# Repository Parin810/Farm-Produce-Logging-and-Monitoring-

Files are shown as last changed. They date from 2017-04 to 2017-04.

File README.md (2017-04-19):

# eYSIP-2016-Farm-Produce-Logging-and-Monitoring

#####This project consist of following folders
 **Final code:** This folder contains all the final and documented code
 
 **tests:** This folder contains all the programs file which is used to test the different component
 
 **shop:** Contains all the files related to opencart website

 **Weighing Machine Design:** Contains all the solidworks cad file for design of our weighing platform. It also contains DXF files for laser cutting parts inside lasercut folder.
 
 **User Manual:** contains the guidlines, how to use the product.
 
 **Poster:** Contains png and svg file for final poster
 
 **Final report:** Contains latex porject for final report
 
 **progress-presentation-1:** Latex project for first presentation

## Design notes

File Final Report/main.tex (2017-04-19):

\documentclass[a4paper,12pt,oneside]{book}

%-------------------------------Start of the Preable------------------------------------------------
\usepackage[english]{babel}
\usepackage{blindtext}
%packagr for hyperlinks
\usepackage{hyperref}
\hypersetup{
    colorlinks=true,
    linkcolor=blue,
    filecolor=magenta,      
    urlcolor=cyan,
}

\urlstyle{same}
%use of package fancy header
\usepackage{fancyhdr}
\setlength\headheight{26pt}
\fancyhf{}
%\rhead{\includegraphics[width=1cm]{logo}}
%\lhead{\rightmark}
%\rhead{\includegraphics[width=1cm]{logo}}
\fancyfoot[RE, RO]{\thepage}
\fancyfoot[CE, CO]{\href{http://www.e-yantra.org}{www.e-yantra.org}}

\pagestyle{fancy}

%use of package for section title formatting
\usepackage{titlesec}
\titleformat{\chapter}
  {\Large\bfseries} % format
  {}                % label
  {0pt}             % sep
  {\huge}           % before-code
 
%use of package tcolorbox for colorful textbox
\usepackage[most]{tcolorbox}
\tcbset{colback=cyan!5!white,colframe=cyan!75!black,halign title = flush center}

\newtcolorbox{mybox}[1]{colback=cyan!5!white,
colframe=cyan!75!black,fonttitle=\bfseries,
title=\textbf{\Large{#1}}}

%use of package marginnote for notes in margin
\usepackage{marginnote}

%use of packgage watermark for pages
%\usepackage{draftwatermark}
%\SetWatermarkText{\includegraphics{logo}}
\usepackage[scale=2,opacity=0.1,angle=0]{background}
\backgroundsetup{
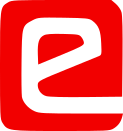
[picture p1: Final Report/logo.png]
contents={}
}

%use of newcommand for keywords color
\usepackage{xcolor}
\newcommand{\keyword}[1]{\textcolor{red}{\textbf{#1}}}

%package for inserting pictures
\usepackage{graphicx}

%package for highlighting
\usepackage{color,soul}

%new command for table
\newcommand{\head}[1]{\textnormal{\textbf{#1}}}

%----------------------End of the Preamble---------------------------------------

\begin{document}

%---------------------Title Page------------------------------------------------
\begin{titlepage}
\raggedright
{\Large eYSIP2016\\[1cm]}
{\Huge\scshape Farm Produce: Logging And Monitoring \\[.1in]}
\vfill
\begin{flushright}
{\large Bhavesh Jadav \\}
{\large Ankur Panwar \\}
{\large MENTORS\hspace{.1in}:}
{\large Saurav Shandilya\\}
{\large Parin Chheda\\}
{\Large Vishwanathan\\}
{\large Duration of Internship: $ 27/05/2016-10/07/2016 $ \\}
\end{flushright}

{\itshape 2016, e-Yantra Publication}
\end{titlepage}
%-------------------------------------------------------------------------------

\chapter[Project Tag]{Farm Produce: Logging And \\ Monitoring}
\section*{Abstract}
This project logs crop data in a green house to reduce manual labour. Essentially, it is a weighing machine connected to Internet.\\
A weighing machine will be delivered to user which can measure weight of crop by using load cell. User can input information related to crop via keypad. User will be assisted by continuous messages on screen. After successful data entry the data will automatically pushed to database. Local people can also take advantage of crop production by placing order through e-commerce website after filling details.

\subsection*{Completion Status}
The project is successfully completed providing "weighing platform, screen, keypad, e-commerce website, admin-panel and user manual." 

\section{Hardware Parts}
\begin{itemize}
  \item Hardware parts
    \begin{itemize}
      \item Load cell
      \item 20x4 LCD
      \item 4x4 Keypad
      \item Raspberry pi 2 Model B
      \item LM2596 step-down voltage regulator
      \item HX711(ADC amplifier)
      \item USB Camera
      \item DC Adapter
      \item Enclosure to hold all parts
    \end{itemize}
  \item Detail of each hardware:\\
    \href{https://cdn.sparkfun.com/datasheets/Sensors/ForceFlex/hx711_english.pdf}{HX711 ADC Amplifier}\\
    \href{http://www.kadcontrols.com/KadWebsite/LoadCell_Tech/CZL601.pdf}{Load cell CZL601}\\
    \href{http://www.onsemi.com/pub_link/Collateral/LM2596-D.PDF}{Step down voltage regulator}\\
    \href{http://lispol.com/uploaded/products_files/1364491305_79923300.pdf}{20x4 LCD}\\
    \href{https://www.parallax.com/sites/default/files/downloads/27899-4x4-Matrix-Membrane-Keypad-v1.2.p    df}{Membrane Keypad}\\
     \href{https://cdn-shop.adafruit.com/pdfs/raspberrypi2modelb.pdf}{Raspberry pi 2 Model B}\\
     \href{https://www.parallax.com/sites/default/files/downloads/27899-4x4-Matrix-Membrane-Keypad-v1.2.pdf}{4x4 Keypad}\\
  
\end{itemize}

\section{Software Used}
\begin{itemize}
   \item List of software used
  \begin{itemize}
   \item  win32 disk imager
   \item  Raspbian wheezy
   \item Notepad++
   \item Local server(xampp apache)
   \item Mysql(xampp)
   \item Diptrace
   \item Corel draw
   \item Autodesk Autocad
   \item Solidworks
   \item Atom text editor
   \item Opencart framework
  \end{itemize}
\end{itemize} 
\begin{itemize}
   \item link of software: \\
  \href{https://sourceforge.net/projects/win32diskimager/}{win32 disk imager}\\
  \href{https://www.raspberrypi.org/downloads/}{Raspbian OS}\\
  \href{https://www.apachefriends.org/download.html}{Xampp}\\
  \href{https://notepad-plus-plus.org/download/v6.9.2.html}{Notepad++}\\
  \href{http://diptrace.com/download-diptrace/}{Diptrace}
\end{itemize}

\section{Assembly Of Hardware}
\subsection*{Dimensions Of Enclosure}
\begin{figure}[!htb]
\minipage{0.24\textwidth}
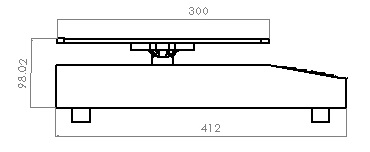
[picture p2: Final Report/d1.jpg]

\caption{Side View}
\endminipage\hfill
\minipage{0.24\textwidth}
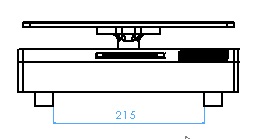
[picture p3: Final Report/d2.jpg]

\caption{Front View}
\endminipage\hfill
\minipage{0.24\textwidth}

\caption{Bottom View}
\endminipage
\end{figure}}
\begin{figure}[!htb]
\minipage{0.24\textwidth}
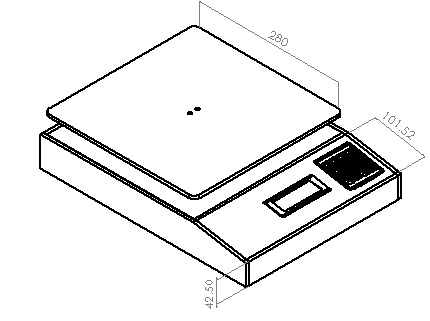
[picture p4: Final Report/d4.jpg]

\caption{Isometric View}
\endminipage\hfill
\minipage{0.24\textwidth}
%\includegraphics[width=\linewidth]{d2.jpg}
%\caption{Front View}
\endminipage\hfill
\minipage{0.24\textwidth}
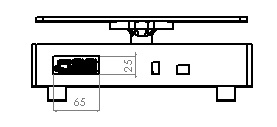
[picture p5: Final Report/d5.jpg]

\caption{Back View}
\endminipage
\end{figure}}
\subsection*{Block Diagram}

\subsection*{Connection Diagram}\\\\
\begin{figure}[!htb]
\minipage{0.24\textwidth}
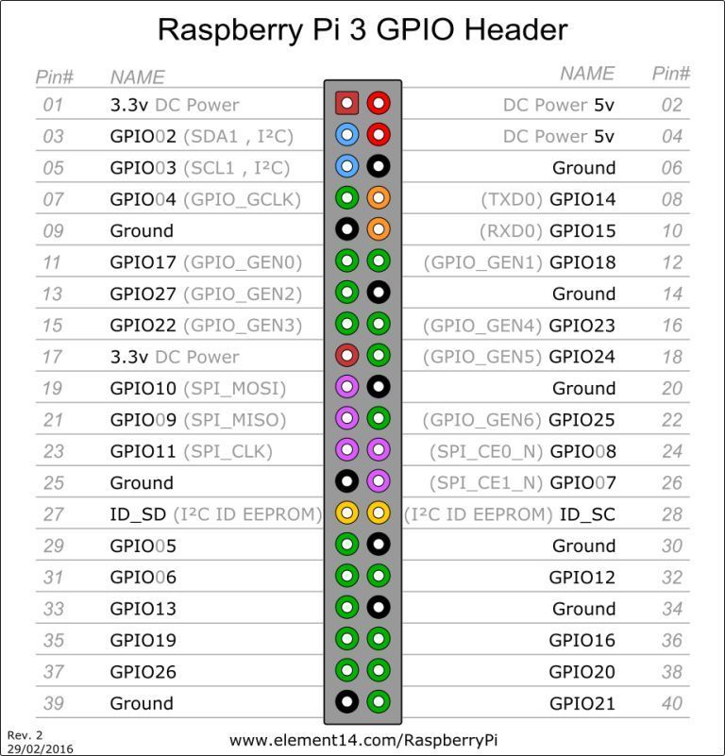
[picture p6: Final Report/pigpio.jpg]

\caption{Rpi pin-out}
\endminipage\hfill
\minipage{0.24\textwidth}
%\includegraphics[width=2cm,height=2cm]{lcd.png}
%\caption{LCD pin-out}
\endminipage\hfill
\minipage{0.24\textwidth}
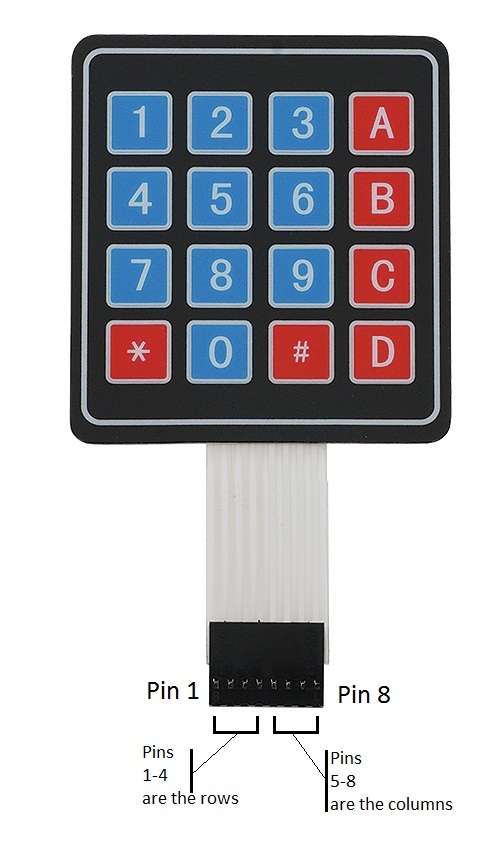
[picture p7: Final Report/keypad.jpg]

\caption{Keypad pin-out}
\endminipage
\end{figure}}
%\item Raspberry pi pinout \includegraphics[height=7cm,width=6cm]{pigpio.jpg}\\

\begin{figure}[!htb]
\minipage{0.24\textwidth}
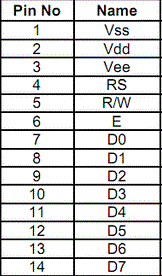
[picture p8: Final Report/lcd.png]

\caption{LCD pin-out}
\endminipage\hfill
\minipage{0.24\textwidth}
%\includegraphics[width=2cm,height=2cm]{lcd.png}
%\caption{LCD pin-out}
\endminipage\hfill
\minipage{0.24\textwidth}

\caption{load cell pin-out}
\endminipage
\end{figure}}

\subsection{Schematic Interface Between Modules}
\begin{figure}[!htb]
\minipage{0.24\textwidth}
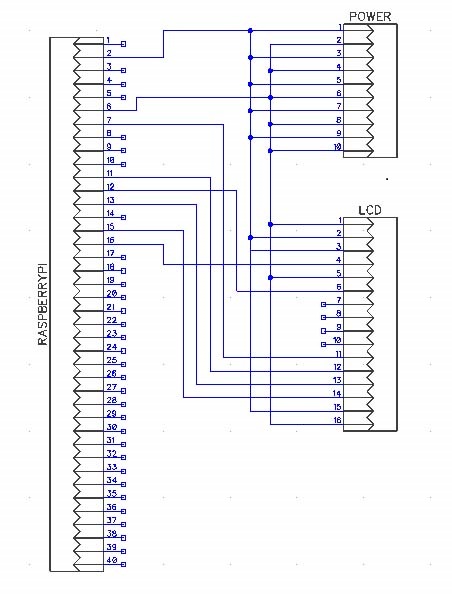
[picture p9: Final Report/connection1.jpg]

\caption{Rpi, power and LCD}
\endminipage\hfill
\minipage{0.24\textwidth}

\caption{Rpi and Load cell}
\endminipage\hfill
\minipage{0.24\textwidth}
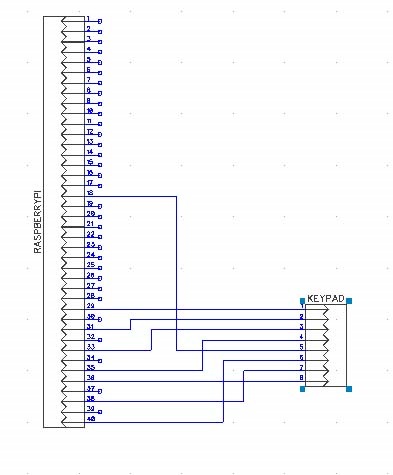
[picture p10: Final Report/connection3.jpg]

\caption{Rpi and keypad}
\endminipage
\end{figure}}
%\item Keypad pinout \includegraphics[height=12cm, width=7cm]{keypad.jpg}\\

\section{Software And Code}
\href{https://github.com/eYSIP-2016/eYSIP-2016-Farm-Produce-Logging-and-Monitoring/tree/master}{Github link}\\\\
e-Commerce website\\\\
\\

\subsection*{Assembling Steps}
The dimension of the machine is 40x30x11.5cm. More detailed version of model can be found on github.\\\\
\\
Step 1: Attach side plates, front plate, middle plate and back plate by using L clamps as shown in above diagram.\\\\\\
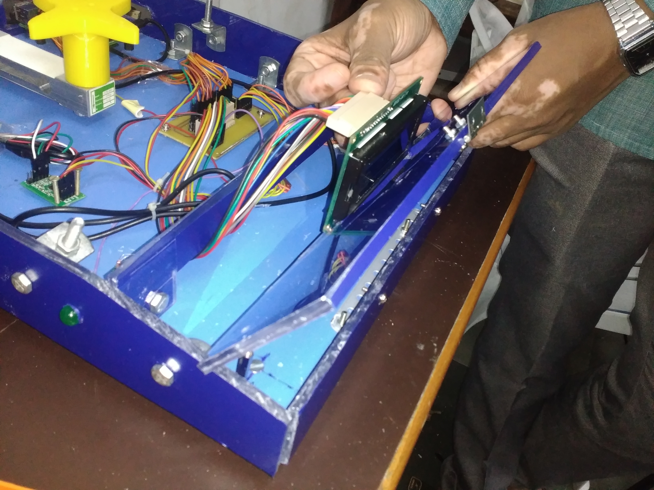
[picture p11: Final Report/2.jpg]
\\
Step 2: Place LCD on front panel. Use 20x4 LCD.\\
\\
Step 3: Use four 3mm screws with bolts to fix the LCD on panel. After attaching LCD, Attach keypad to the front panel\\\\\\
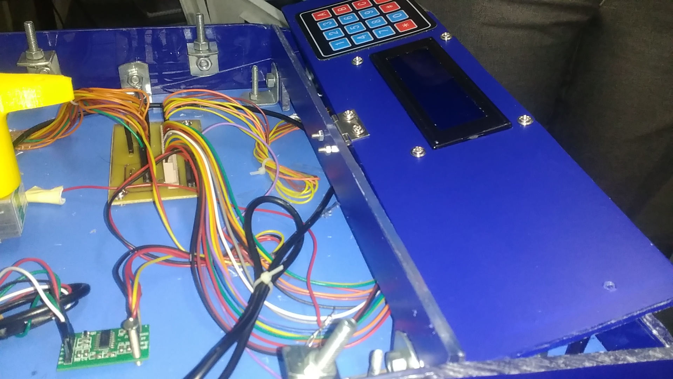
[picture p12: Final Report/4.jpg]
\\
Step 4: Attach front panel to the middle plate with the help of hinge. Use 3mm screws with bolts to attach front panel to middle plate.\\
\\
Step 5: After attaching front panel, place the second top most plate over 4 screws attached with side plates. After
putting the plate, user four nuts to fix the plate.\\\\\\
\\ 
Step 6: Attach weighing platform on top of star shaped design and use 3mm screws with nuts to fix it.\\
\\
Step 7: Finlay attach camera stand at side of the machine.\\

\section{Final Product}
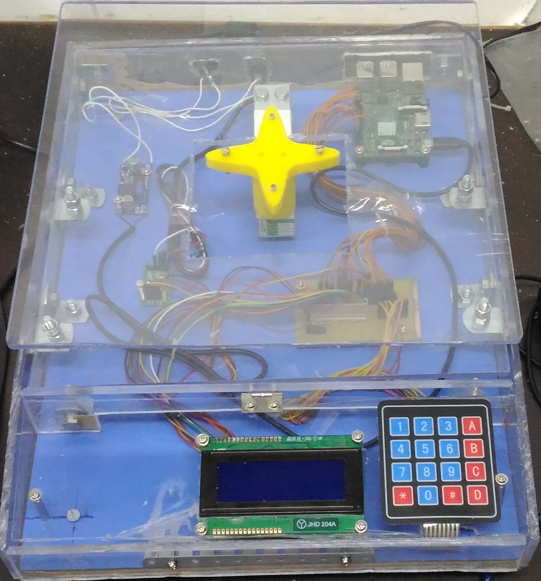
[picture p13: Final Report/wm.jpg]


\section{Future Work}
In future this project can be made more effective by using image processing to identify which crop is put on the machine. We can also include bar-code or RFID module which will contain all the information about crop.\\
We can replace membrane keypad and LCD by touch screen.\\
This model can be transformed into more compact version.\\

\section{Bug Report And Challenges}
\begin{itemize}
\item Bug
\begin{itemize}
   \item Currently e-commerce website is unable to sent email to users using SMTP server.
   \item Two way handshaking between server and machine is not implemented yet. Although it is a rare situation, data might get lost some times while transferring it to server because tow way hand shaking is not implemented yet
\end{itemize}
\item Challenges
\begin{itemize}
   \item Building enclosure of weighing machine.
   \item Calibration of load cell.
   \item De-bouncing of keypad.
\end{itemize}
\end{itemize}
\begin{thebibliography}{li}
\bibitem{wavelan97} eyantra community\\
\bibitem{wavelan97} https://grabcad.com/library/keypad-4x4-membrane-1\\
\bibitem{wavelan97} http://www.tutorialspoint.com/python/python\_functions\\
\bibitem{wavelan97} http://www.tutorialspoint.com/python/python\_database\_access\\
\bibitem{wavelan97} https://grabcad.com/library/20x4-lcd-1\\
\bibitem{wavelan97} https://grabcad.com/library/raspberry-pi-model-b-2\\
\bibitem{wavelan97} http://forum.opencart.com/\\
\bibitem{wavelan97} http://stackoverflow.com/\\
\bibitem{wavelan97} https://sourceforge.net/p/raspberry-gpio-python/wiki/Inputs/\\
\bibitem{wavelan97} https://www.stewright.me/2014/06/tutorial-install-mysql-server-on-raspberry-pi/\\
\bibitem{wavelan97} https://pyformat.info/\\
\bibitem{wavelan97} http://mysql-python.sourceforge.net/MySQLdb.html\\
\bibitem{wavelan97} https://www.youtube.com/watch?v=nGUpzwEa4vg\\
\bibitem{wavelan97} https://www.youtube.com/watch?v=yYnX5QodqQ4\\
\bibitem{wavelan97} http://playground.arduino.cc/Learning/SoftwareDebounce\\
\bibitem{wavelan97} http://www.raspberrypi-spy.co.uk/2012/07/16x2-lcd-module-control-using-python/\\
\bibitem{wavelan97} http://code.stephenmorley.org/php/creating-downloadable-csv-files/\\
\bibitem{wavelan97} http://www.opencart.com/index.php?route=extension/extension/info\&extension\_id=24594\\
\end{thebibliography}

\end{document}

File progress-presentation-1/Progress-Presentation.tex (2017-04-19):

\documentclass[10pt, a4paper]{beamer}
\usetheme{Berkeley}
\usecolortheme{sidebartab}
\usepackage{graphicx}

\begin{document}
	\setbeamertemplate{sidebar left}{}
	\title{Progress Presentation-II}
	\subtitle{e-Yantra Summer Intership-2016 \\FARM PRODUCE: LOGGING AND MONITORING}
	\author{Bhavesh\\Ankur\\$ $\\$ $ \hspace{-0.7in} Mentors: Saurav\\Parin\\Vishwanathan}
	\institute{IIT Bombay}
	\date{\today}
	%\addtobeamertemplate{sidebar left}{}{\includegraphics[scale = 0.3]{logowithtext.png}}
	\frame{\titlepage}

\setbeamertemplate{sidebar left}[sidebar theme]
\section{Overview of Project}
\begin{frame}{Overview of Project}
	Details Of Project: \\
	\begin{itemize}
		\item NAME: \hspace{0.1in} Farm Produce:Logging And Monitoring

		\item OBJECTIVE:\hspace{0.1in}To help in manual record maintenance which is\\$ $\hspace{0.85in} vulnerable to errors by providing a robust\\$ $\hspace{0.85in} automated system. 
		
		\item Deliverables
		\begin{itemize}
			\item LCD
			\item Keypad
			\item Weighing platform
			\item Interactive web page
		\end{itemize}
	\end{itemize}
\end{frame}

\section{Overview of Task}
\begin{frame}{Overview of Task}
	\begin{tabular}{|c|c|C|}
		\hline	
		Week&Task&Deadline\\	
		\hline\hline
		Week1&Raspberry Pi setup and load cell calibration&-\\
		\hline\hline
		Week2&Interfacing 16*2 LCD and 4*4 Keypad&-\\
		\hline\hline
		Week3&1.Integration of Load cell, Keypad and LCD&-\\
		$   $&2.Image capturing from camera and store it in &$ $ \\
		$   $&a database using sql query&$ $\\
		$   $&3.Inserting data into sql database using python&$ $\\
		\hline\hline
		Week4&1.Integration of all the components&-\\
		$   $&2.web interface showing the weight log and image&$ $\\
		\hline\hline
		Week5&1.Adding features like charts and CSV download&6 days\\
		$	$&2.Assembling the entire project with enclosure&$ $\\
		\hline\hline
		Week6&Testing and documentation&6 days\\
		\hline			
	\end{tabular}
\end{frame}

\section{Task Accomplised}
\begin{frame}{Task Accomplised}
	\textbf{Completed Tasks}
	\begin{itemize}		
		\item Raspberry Pi setup and load cell calibration
		\item Interfacing 16*2 LCD and 4* Keypad
		\item Integration of load cell, Keypad and LCD 
		\item Image capturing from camera and storing in database
		\item Inserting data into sql database using python
		\item Integration of all the components
		\item Web interface showing the weight log and image
	\end{itemize}	
		\textbf{Tasks Left}
	\begin{itemize}	
		\item Adding features like charts and CSV
		\item Assembling the entire project with enclosure
		\item Testing and documentation
	\end{itemize}
\end{frame}

\section{Challenges Faced}
\begin{frame}{Challenges Faced}
	\begin{itemize}
		\item LOAD CELL:\hspace{.1in} Caliberation
		\item LCD:\hspace{.1in} Clear screen
		\item KEYPAD:\hspace{.1in} Debouncing
	\end{itemize}
\end{frame}

\section{Future Plans}
\begin{frame}{Future Plans}
	\begin{itemize}
		\item In future, team is planning to replace LCD and Keypad by Touch screen. 
	\end{itemize}
\end{frame}

\section{Thank You}
\begin{frame}{Thank You}
	\centering THANK YOU !!!
\end{frame}
\end{document}

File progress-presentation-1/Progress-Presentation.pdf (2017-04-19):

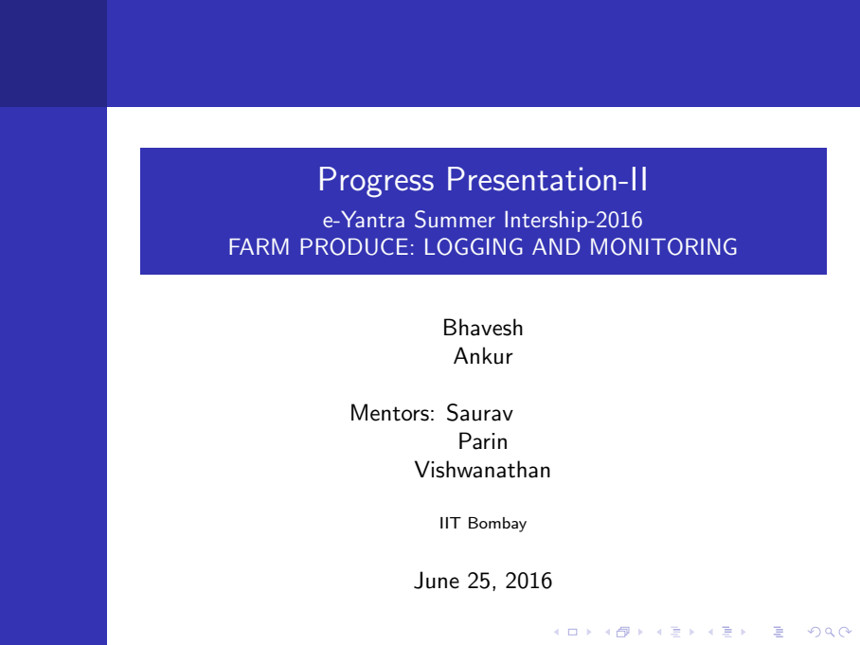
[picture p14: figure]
Progress Presentation-II; e-Yantra Summer Intership-2016 FARM PRODUCE: LOGGING AND MONITORING; Bhavesh Ankur; Mentors: Saurav Parin Vishwanathan; IIT Bombay; June 25, 2016

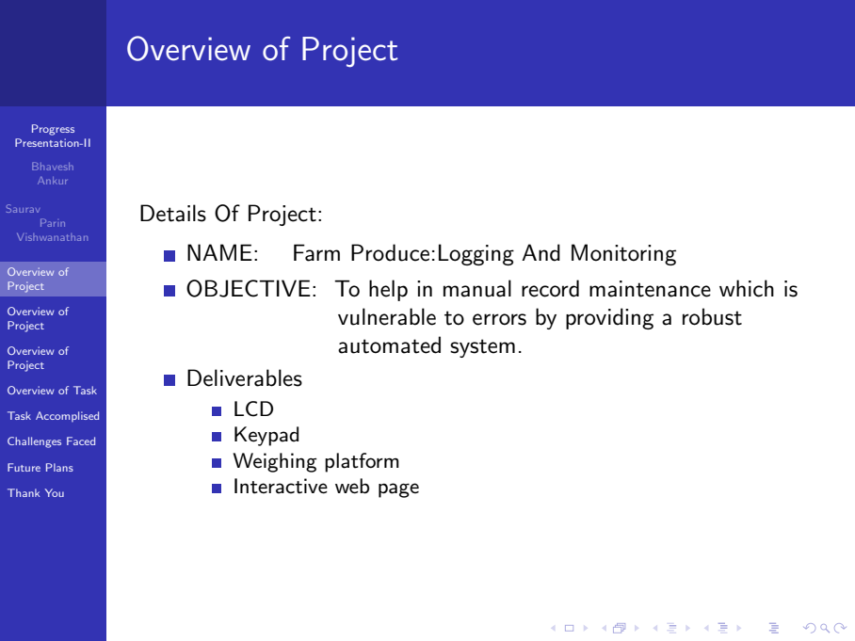
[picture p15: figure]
Progress Presentation-II; Bhavesh Ankur; Mentors:; Saurav; Parin Vishwanathan; Overview of Project; Overview of Task; Task Accomplised; Challenges Faced; Future Plans; Thank You; Details Of Project:; NAME:; Farm Produce:Logging And Monitoring; automated system.; Deliverables; LCD Keypad Weighing platform Interactive web page

OBJECTIVE: To help in manual record maintenance which is vulnerable to errors by providing a robust

Progress
Presentation-II

Bhavesh
Ankur

Mentors: Saurav
Parin
Vishwanathan

Overview of
Project

Overview of
Project

Overview of
Project

Overview of Task

Task Accomplised

Challenges Faced

Future Plans

Thank You

## Overview of Task

Week | Task | Deadline
Week1 | Raspberry Pi setup and load cell calibration | -
Week2 | Interfacing 16*2 LCD and 4*4 Keypad | -
Week3 | 1.Integration of Load cell, Keypad and LCD | -
| 2.Image capturing from camera and store it in a database using sql query 3.Inserting data into sql database using python
Week4 | 1.Integration of all the components | -
| 2.web interface showing the weight log and image
Week5 | 1.Adding features like charts and CSV download | 6 days
| 2.Assembling the entire project with enclosure
Week6 | Testing and documentation | 6 days

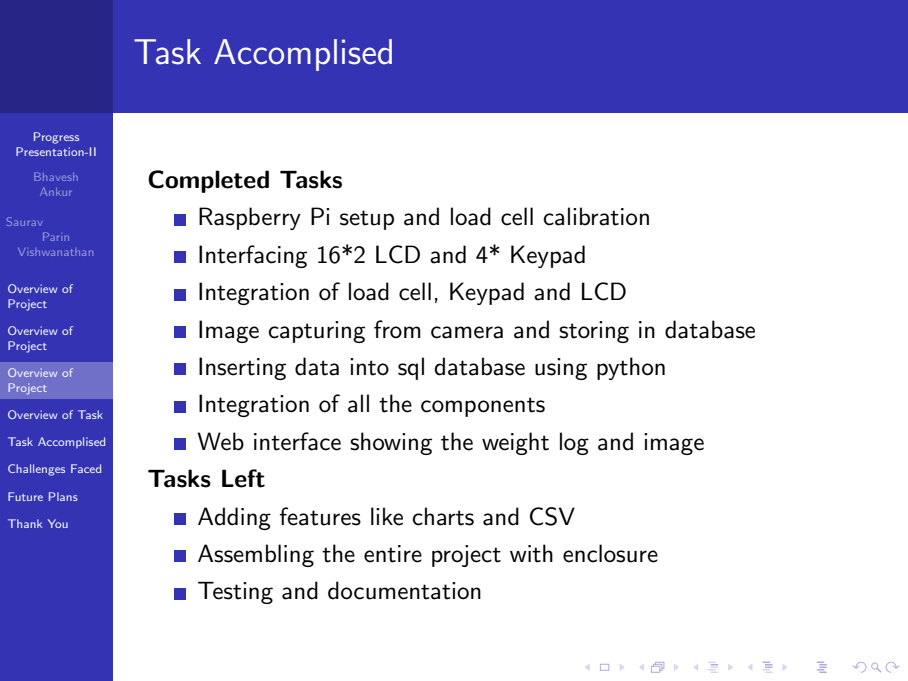
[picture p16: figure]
Progress Presentation-II; Bhavesh Ankur; Mentors:; Saurav; Parin Vishwanathan; Overview of Project; Overview of Task; Task Accomplised; Challenges Faced; Future Plans; Thank You; Completed Tasks; Interfacing 16*2 LCD and 4* Keypad; Integration of all the components; Tasks Left; Adding features like charts and CSV; Testing and documentation

Raspberry Pi setup and load cell calibration

Integration of load cell, Keypad and LCD
Image capturing from camera and storing in database Inserting data into sql database using python

Web interface showing the weight log and image

Assembling the entire project with enclosure

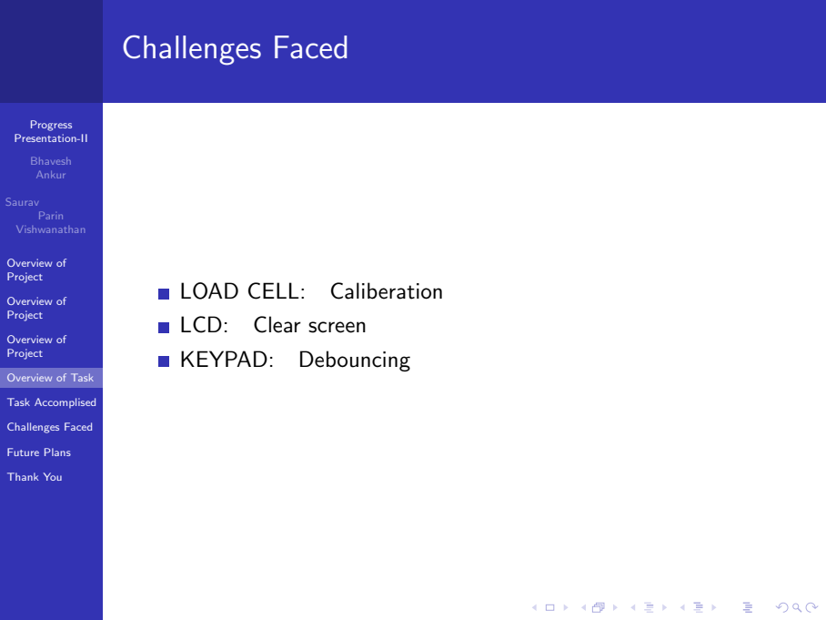
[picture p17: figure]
Progress Presentation-II; Bhavesh Ankur; Mentors:; Saurav; Parin Vishwanathan; Overview of Project; Overview of Task; Task Accomplised; Challenges Faced; Future Plans; Thank You; LOAD CELL: Caliberation; LCD: Clear screen; KEYPAD: Debouncing

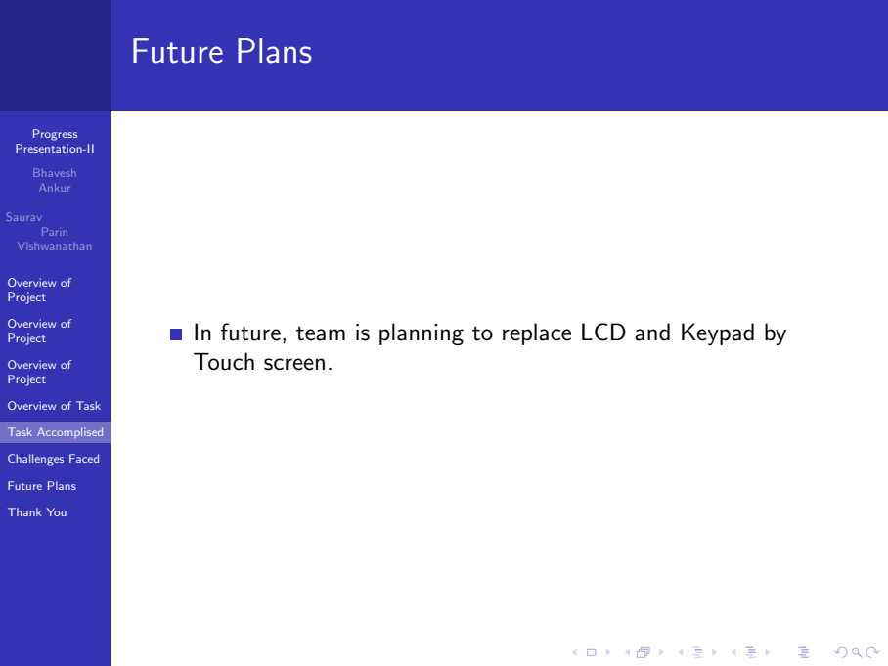
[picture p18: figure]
Progress Presentation-II; Bhavesh Ankur; Mentors:; Saurav; Parin Vishwanathan; Overview of Project; Overview of Task; Task Accomplised; Challenges Faced; Future Plans; Thank You; Touch screen.

In future, team is planning to replace LCD and Keypad by

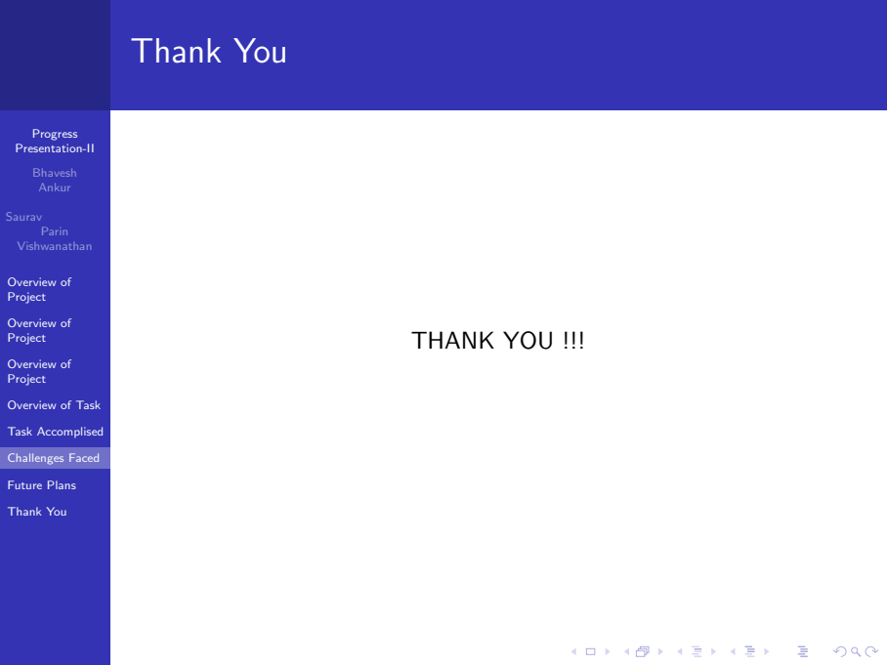
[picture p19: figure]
Progress Presentation-II; Bhavesh Ankur; Mentors:; Saurav; Parin Vishwanathan; Overview of Project; Overview of Task; Task Accomplised; Challenges Faced; Future Plans; Thank You; THANK YOU !!!

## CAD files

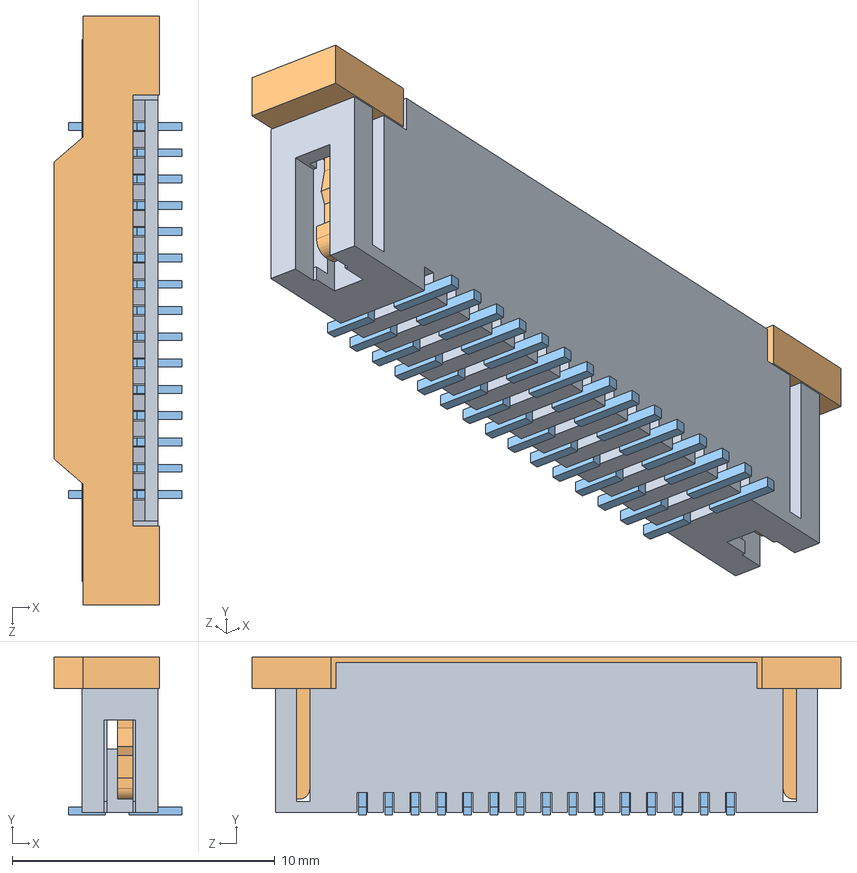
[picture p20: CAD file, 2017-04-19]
Weighing Machine Design/rpi/raspberry_pi_B+_(15_pin_FFC_Connector).SLDASM
4.85 x 6.00 x 22.4 mm
raspberry_pi__15_pin_FFC_Connector_body
raspberry_pi__15_pin_FFC_Connector_locker
raspberry_pi__15_pin_FFC_Connector_pins x 15

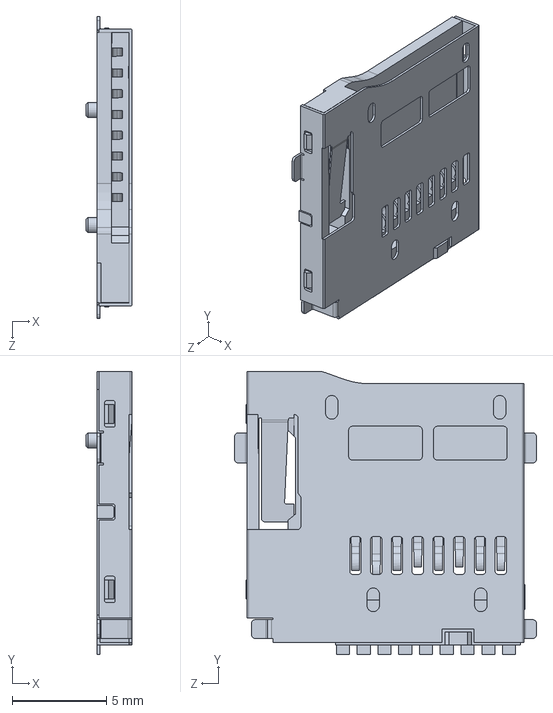
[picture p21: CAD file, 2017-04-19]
Weighing Machine Design/rpi/raspberry_pi_B+_(slot).SLDASM
2.44 x 15.0 x 16.0 mm

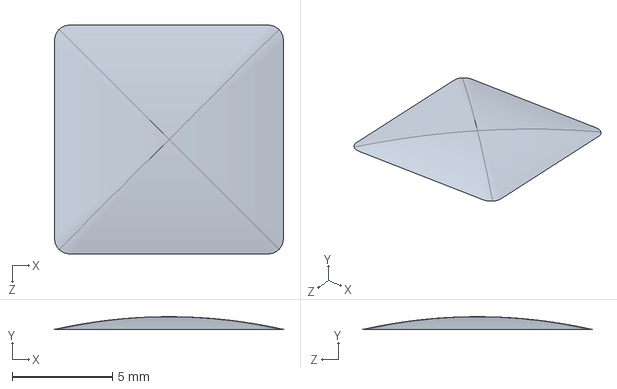
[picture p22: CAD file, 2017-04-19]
Weighing Machine Design/keypad.SLDASM
11.4 x 0.635 x 11.4 mm

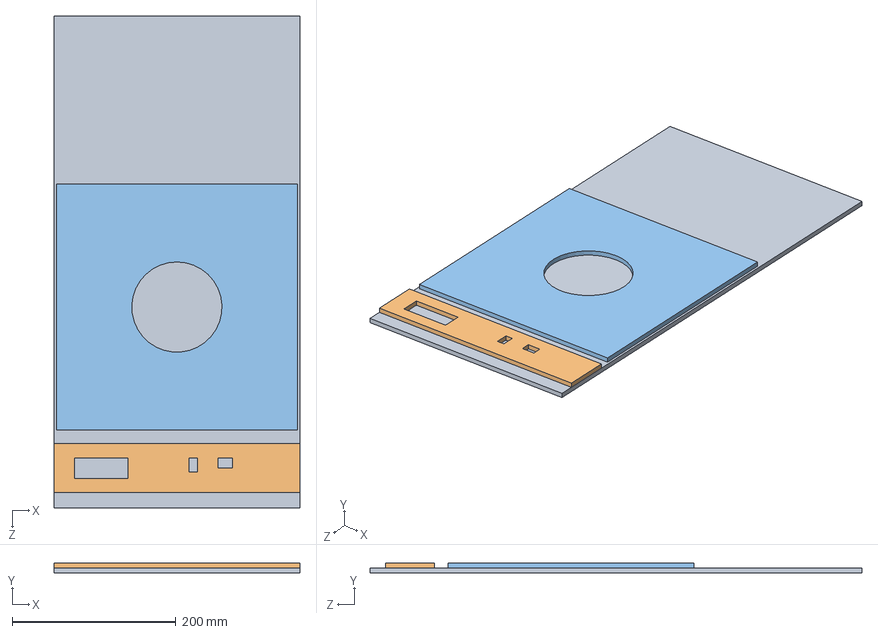
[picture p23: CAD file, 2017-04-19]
Weighing Machine Design/plate2.SLDASM
300.0 x 12.0 x 600.0 mm
cncdimensiion
BackPlate
topplate

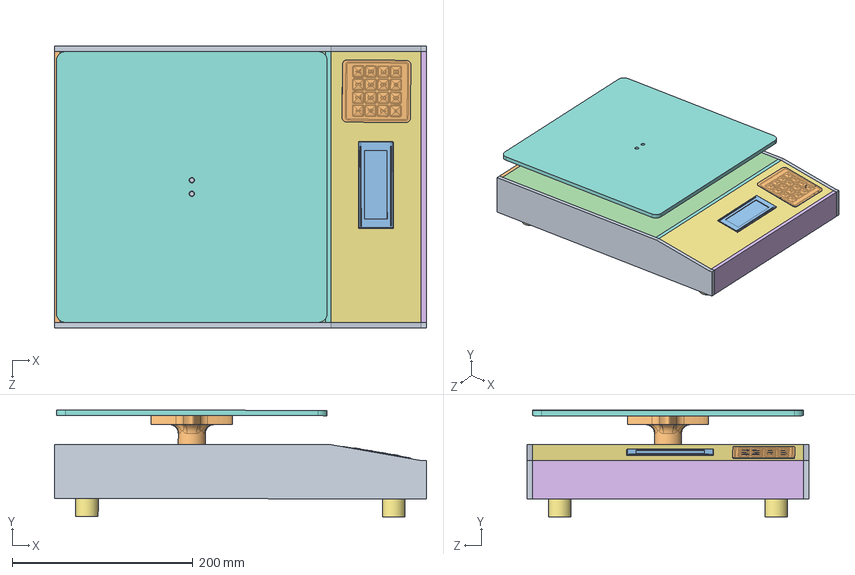
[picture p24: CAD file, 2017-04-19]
Weighing Machine Design/Model.SLDASM
412.0 x 118.4 x 312.0 mm
baseplate
BackPlate
loadcell
topplate
basecylinder
frontplate
FrontPanel
Middleplate
sidepanels
keypad-16KeyMembrane1
20X4LCD JHD204A
raspberry_pi_B+_(bar_180_2x20)
raspberry_pi_B+_(QFN64)
raspberry_pi_B+_(168_FBGA_12x12)
raspberry_pi_B+_(USB_x2_part1) x 2
raspberry_pi_B+_(USB_x2_part2) x 2
raspberry_pi_B+_(micro_USB_cover)
raspberry_pi_B+_(micro_USB_contacts)
raspberry_pi__HDMI_socket_cover
raspberry_pi__HDMI_socket_inside
raspberry_pi__HDMI_socket_large_pin x 10
raspberry_pi__HDMI_socket_small_pin x 9
raspberry_pi_B+_(RJ45)
raspberry_pi__15_pin_FFC_Connector_body x 2
raspberry_pi__15_pin_FFC_Connector_locker x 2
raspberry_pi__15_pin_FFC_Connector_pins x 30
raspberry_pi_B+_(CI_Board)
raspberry_pi_B+_(microsd_slot2)
raspberry_pi_B+_(microsd2)
raspberry_pi_B+_(audio_video2)
feet x 4
WeighingPlateform
sidepanels2

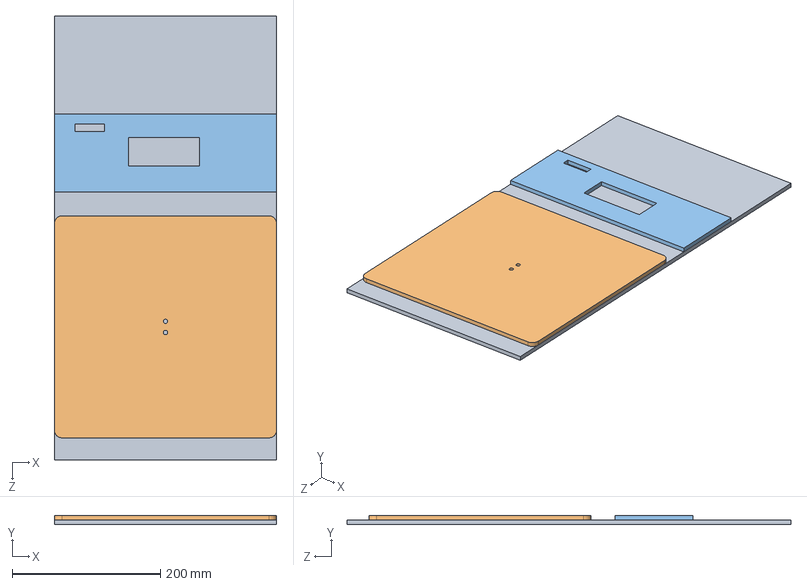
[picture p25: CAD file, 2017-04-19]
Weighing Machine Design/plate3.SLDASM
300.0 x 12.0 x 600.0 mm
cncdimensiion
WeighingPlateform
frontpanelcut

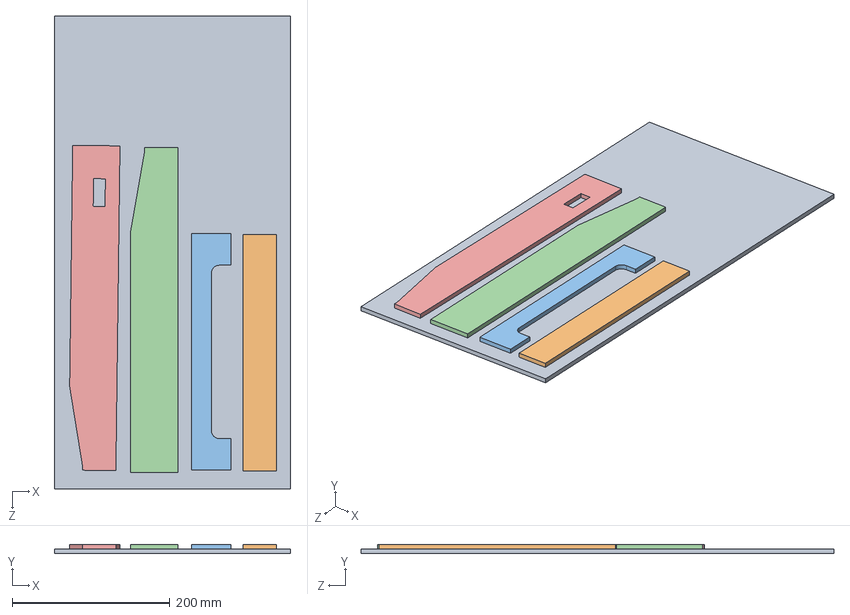
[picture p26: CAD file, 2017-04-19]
Weighing Machine Design/plate1.SLDASM
300.0 x 12.0 x 600.0 mm
cncdimensiion
frontplate
Middleplate
sidepanels
sidepanels2

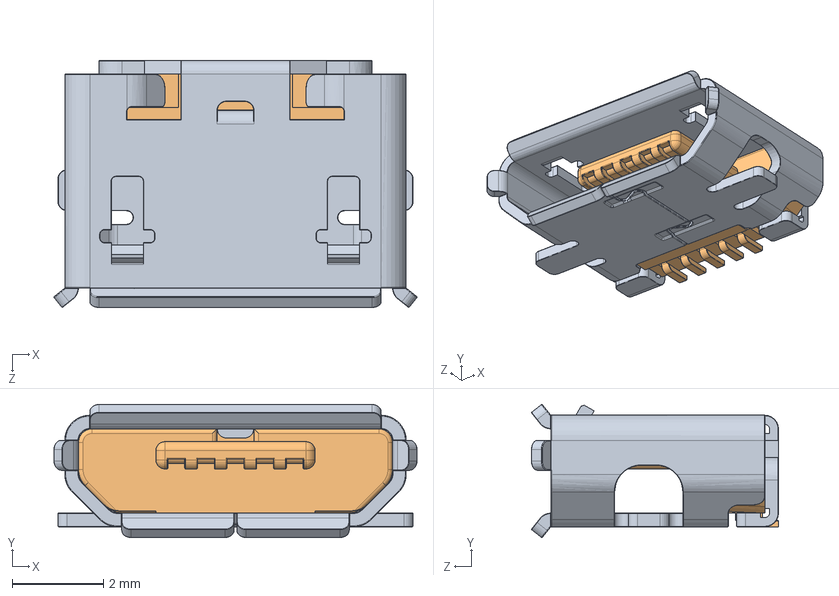
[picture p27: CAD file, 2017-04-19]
Weighing Machine Design/rpi/raspberry_pi_B+_(micro_USB).SLDASM
7.97 x 2.92 x 5.43 mm
raspberry_pi_B+_(micro_USB_cover)
raspberry_pi_B+_(micro_USB_contacts)

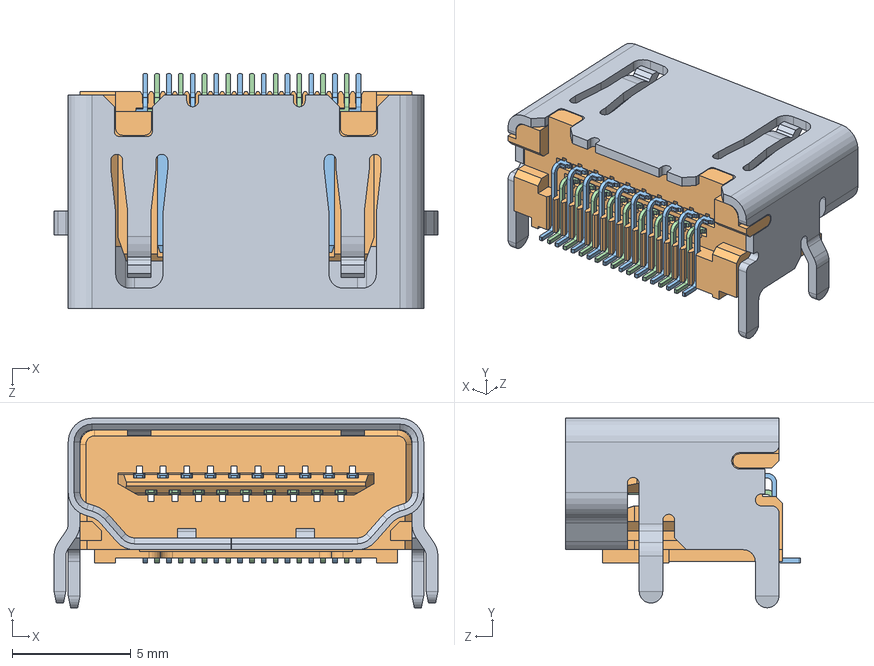
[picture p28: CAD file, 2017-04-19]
Weighing Machine Design/rpi/raspberry_pi_B+_(HDMI_socket).SLDASM
16.2 x 8.00 x 9.90 mm
raspberry_pi__HDMI_socket_cover
raspberry_pi__HDMI_socket_inside
raspberry_pi__HDMI_socket_large_pin x 10
raspberry_pi__HDMI_socket_small_pin x 9

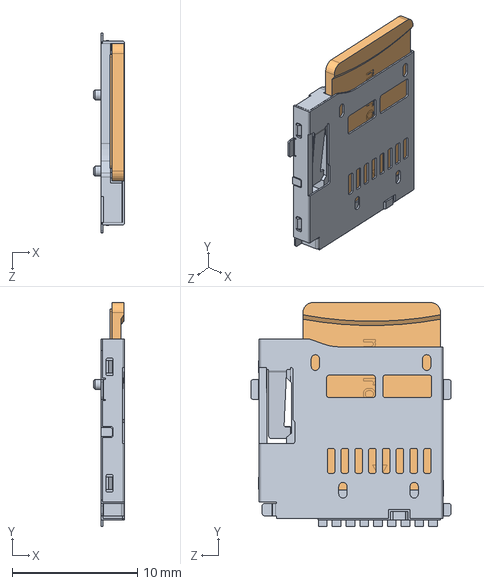
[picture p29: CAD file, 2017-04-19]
Weighing Machine Design/rpi/raspberry_pi_B+_(microsd_slot).SLDASM
2.44 x 17.9 x 16.0 mm
raspberry_pi_B+_(slot)
raspberry_pi_B+_(microsd)

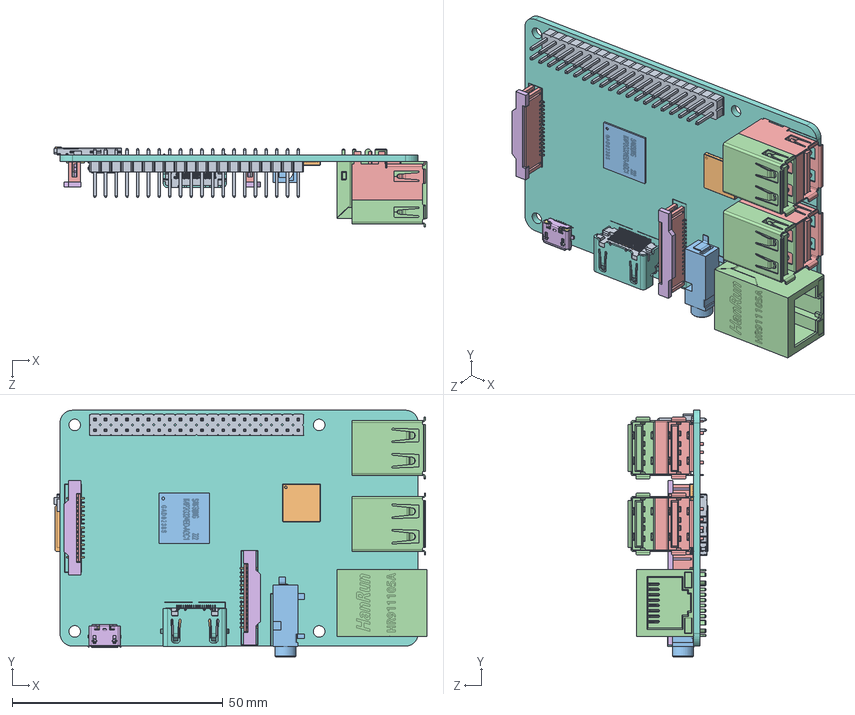
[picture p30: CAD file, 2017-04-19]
Weighing Machine Design/rpi/raspberrypi_b_+_(assembly).SLDASM
88.5 x 58.5 x 18.9 mm
raspberry_pi_B+_(bar_180_2x20)
raspberry_pi_B+_(QFN64)
raspberry_pi_B+_(168_FBGA_12x12)
raspberry_pi_B+_(USB_x2_part1) x 2
raspberry_pi_B+_(USB_x2_part2) x 2
raspberry_pi_B+_(micro_USB_cover)
raspberry_pi_B+_(micro_USB_contacts)
raspberry_pi__HDMI_socket_cover
raspberry_pi__HDMI_socket_inside
raspberry_pi__HDMI_socket_large_pin x 10
raspberry_pi__HDMI_socket_small_pin x 9
raspberry_pi_B+_(RJ45)
raspberry_pi__15_pin_FFC_Connector_body x 2
raspberry_pi__15_pin_FFC_Connector_locker x 2
raspberry_pi__15_pin_FFC_Connector_pins x 30
raspberry_pi_B+_(CI_Board)
raspberry_pi_B+_(microsd_slot2)
raspberry_pi_B+_(microsd2)
raspberry_pi_B+_(audio_video2)

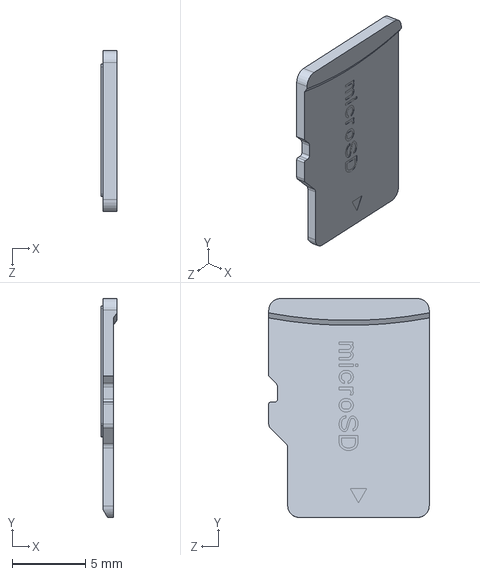
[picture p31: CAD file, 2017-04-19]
Weighing Machine Design/rpi/raspberry_pi_B+_(microsd).SLDASM
1.10 x 15.0 x 11.0 mm

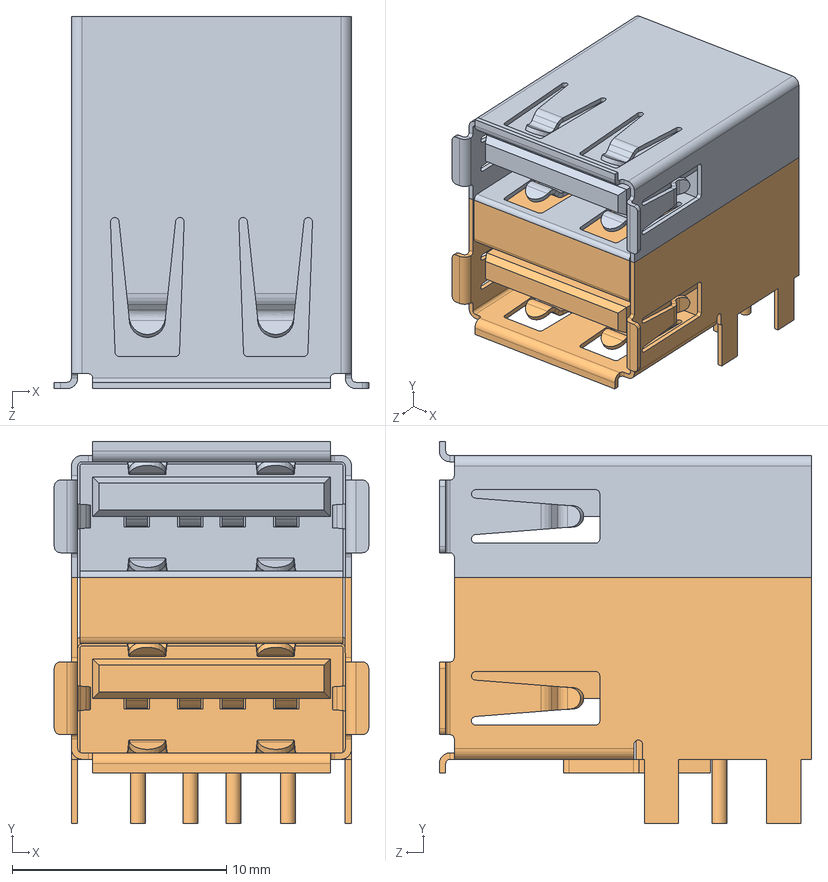
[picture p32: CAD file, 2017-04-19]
Weighing Machine Design/rpi/raspberry_pi_B+_(USB_x2).SLDASM
14.7 x 17.9 x 17.4 mm
raspberry_pi_B+_(USB_x2_part1)
raspberry_pi_B+_(USB_x2_part2)

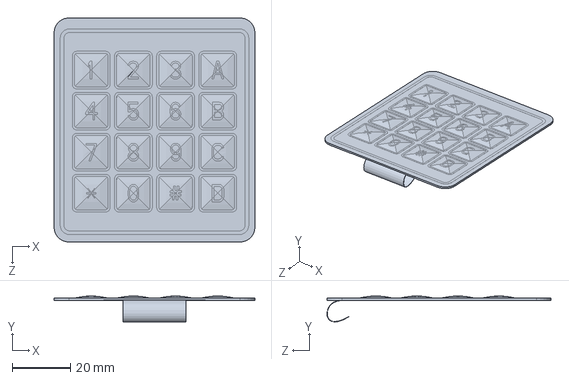
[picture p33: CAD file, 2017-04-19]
Weighing Machine Design/kpad/keypad-16KeyMembrane1.sldprt
69.0 x 8.87 x 76.9 mm

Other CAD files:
Weighing Machine Design/rpi/raspberry_pi_B+_(P1).SLDASM
Weighing Machine Design/lasercut/plate3.DXF
Weighing Machine Design/lcd/20X4LCD JHD204A.STEP
Weighing Machine Design/loadcell.SLDPRT
Weighing Machine Design/BackPlate.SLDPRT
Weighing Machine Design/FrontPanel.SLDPRT
Weighing Machine Design/Middleplate.SLDPRT
Weighing Machine Design/Part_1.sldprt
Weighing Machine Design/WeighingPlateform.SLDPRT
Weighing Machine Design/basecylinder.SLDPRT
Weighing Machine Design/baseplate.SLDPRT
Weighing Machine Design/cncdimensiion.SLDPRT
Weighing Machine Design/cylinder.SLDPRT
Weighing Machine Design/feet.SLDPRT
Weighing Machine Design/frontpanelcut.SLDPRT
Weighing Machine Design/frontplate.SLDPRT
Weighing Machine Design/lasercut/plate1.DXF
Weighing Machine Design/lasercut/plate2.DXF
Weighing Machine Design/lcd/20X4LCD JHD204A.SLDPRT
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

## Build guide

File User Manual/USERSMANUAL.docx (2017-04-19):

USER'S MANUAL

Prerequisites:

1. Plug DC adapter for power supply, you can use 9 volt as well as 12 volt DC adapter. Minimum current requirement is 1 Amps.
2. Camera must be connected via USB port. You can find USB port at the back of the machine.
3. After plugging DC adapter turn on the switch at the back.

Direction:

1. When you start the machine, you won’t be able to see anything on LCD screen. It will take 10 to 20 seconds for some message to be appear on LCD screen. If you can’t see anything on LCD screen then refer to ‘Debugging’ section at the bottom of this manual.
2. “ Welcome remove any object..” when this text appears on LCD as shown in fig 1., you can proceed.

fig. 1

3. If appears “failed to fetch crop info” as shown in fig. 2 it states that fetching any update from database was unsuccessful. This can happen if machine is not connected to internet. If you want to get updates then check your internet connection or press ‘B’ to restart the script.

fig. 2

4. “Place your object….” Do as written on screen of weighing machine. Once you put object on the weighing platform, weight of the object will appear in grams at the last line as shown in fig. 3

Fig. 3

5. If you wants to tare the weight of the object which is on weighing platform then press ‘D’. Taring of weight can be ONLY done when weight of object is displayed on the screen.
6. After place object on the weighing platform, press ‘*’ to go to the next step. Next step is to enter Crop ID. Enter crop ID and press ‘*’ to confirm the Crop ID as shown in fig. 4

fig. 4

7. Next step is to enter Trough ID. Enter the trough ID and press ‘*’ to confirm the Trough ID as shown in fig. 5

fig. 5

8. After entering Trough ID next step is to enter Location ID. Enter Location ID and press ‘*’ Button to confirm as shown in fig. 6

fig. 6

9. For steps 6, 7 and 8:
  a. If mistyped then use “#” button to backspace.
  b. If you enter anything wrong for example if you enter Trough ID wrong the it will show you an error and you won’t be able to proceed further.
10. If it appears “Failed no camera attached” as shown in fig. 7, then check camera connection properly.

fig. 7

11. “Successful” states that your data have been stored in database as shown in fig. 8.

Fig. 8

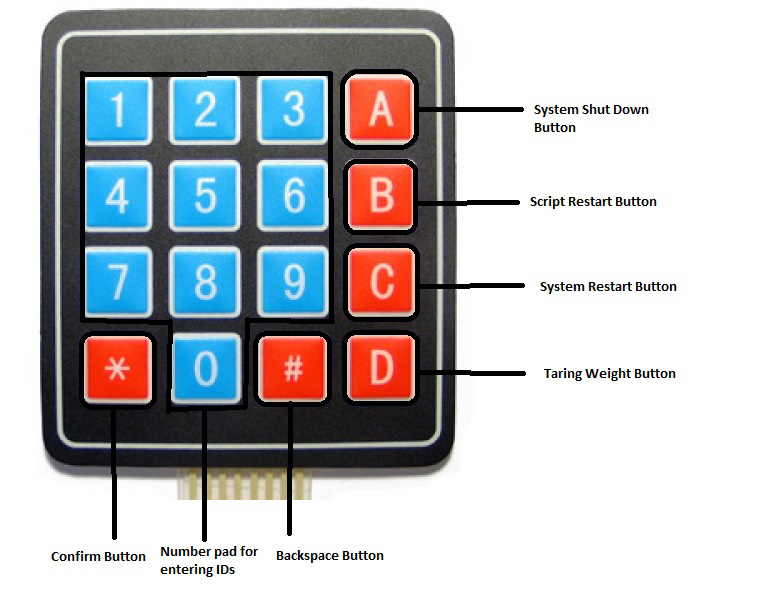
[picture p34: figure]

Fig. 9 Keypad Button Mapping

If something went wrong!!

1. Press button “B” to restart script only.
2. Press button ‘C’ to restart the whole system.

After restarting the script or restarting the system if it still not working properly then follow the steps mentioned in ‘Debugging’ Section which you can find at the bottom of the manual.

To Shutdown the system:

Press button ‘A’ to shutdown the system. After shutting down notice the green LED at the left side of machine. DO NOT turn off machine from the plug while this green led is on. When you shutdown the system after pressing ‘A’

Debugging:

- When you start the machine and you are not seeing anything on LCD screen after a long period of time. Then make sure that LCD is working properly. Open the front panel by removing two screws on top of front panel and check the connection of LCD. If you want to find that LCD is working or not press ‘A’ button on keypad. It will shutdown the system and green LED at the left side of machine will go off. While shutting down the system if you can’t see anything on LCD screen then replace the LCD screen with new one.
- At start of the system, when system fails to fetch information from server then restart the script. After restarting the script if problem still persist then make sure you are connected to internet and systems’s IP address is configured properly.
- If you see message ‘Camera not attached’ on LCD screen then attach the USB camera in the USB port which you can find at the back of the machine. If camera is attached and it still showing ‘Camera not attached’ then check camera connection or attach new camera.

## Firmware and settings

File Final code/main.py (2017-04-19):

'''
*
* Project: 	   		Farm Produce: Logging and Monitoring
* Author: 			Bhavesh Jadav
* Filename:    		main.py
* Functions: 			init()
*					tare()
*					calculateWeight()
*					displayWeight()
*					acceptCropID()
*					acceptTroughID()
*					acceptLocationID()
*					fetchCropInfo()
*					fetchCropInfoFromServer()
*					fetchTroughInfoFromServer()
*					takePicture()
*					storedata()
* Global Variables:	baseValue
*					taredWeight
*					imgName
*					measuredWeight
*					DOUT
*					toughID
*					cropID
*					cropName
*					locationName
*					troughIDExcepted
*					locationIDExcepted
*					cropIDExcepted
*					pictureTaken
*					active
* 					server
*
'''

import loadcell as lc #import load cell library
import MySQLdb as sqldb #import mysql library
import RPi.GPIO as GPIO
import lcd	#import lcd library
import kpad	#import keypad library
import time
import os
import math
import datetime
import sys

#address constant for lines in lcd display
LINE_1 = 0x80
LINE_2 = 0xC0
LINE_3 = 0x94
LINE_4 = 0xD4

#change below variable with server IP
server = "169.254.48.23"

baseValue = 0  #variable to store the base value of load cell
taredWeight = 0  #variable to store tared weight
imgName = 0  #variable to store image name
measuredWeight = 0.0  #variable to store calculated weight
DOUT = 22  #constant stores gpio pin used by dout pin of hx711. It will be used to check if hx711 is ready to send data or not
troughID = ""  #variable to sotre trough ID
locationID = "" #variable to sotre location ID
cropID = ""  #variable to store crop ID
cropName = ""  #variable to store crop name
locationName = ""  #variable to store location name

#Flag variables
troughIDExcepted = 0  #to check if trough id is accepted or not
locationIDExcepted = 0  #to check if location id is accepted or not
cropIDExcepted = 0	#to check if crop id is accepted or not
pictureTaken = 0	#to check if picture is taken or not
active = 1	#to check if program is active or not

#defining some database variable
host = "localhost"
username = "root"
password = "firebird"

#initialize lcd
lcd.lcd_init()

'''
*
* Function Name: 	calculateWeight
* Input: 				none
* Output: 			returns the calculated weight from the load cell value
* Logic: 				1) take the reading from load cell
*					2) take the difference between current value and base value
*					3) divide the difference with diference got with known weight
*					4) finally multiply the division answer with known weight value to get the weight
* Example Call:		calculateWeight()
*
'''
def caculateWeight():
	"function to calculate weight"
	global taredWeight
	global measuredWeight
	global baseValue
	val = lc.read_cell_value()  #read load cell value
	weight = ((baseValue - val) / 49000.0) * 230.0  #convert them into weight
	weight = weight - taredWeight  #remove tared weight from calculated weight
	if weight < 0:	#if weight becomes negative then set it back to zero
		weight = 0
	weight = int(weight)
	measuredWeight = weight	#sotre weight into measuredWeight variable
	return measuredWeight	#return the calculated weight

'''
*
* Function Name: 	displayWeight
* Input: 				none
* Output: 			none
* Logic: 				it displays weight on the lcd screen by using calculateWeight function
* Example Call:		displayWeight()
*
'''
def displayWeight() :
	"function to display weight on lcd screen"
	#if there is no weight on the platform display simple message
	if measuredWeight < 10:
		lcd.string("Place your object on", LINE_1)
		lcd.string("the platform", LINE_2)
	#else prompt user to continue by pressing * button
	else:
		lcd.string("Press * button to", LINE_1)
		lcd.string("continue.", LINE_2)
	lcd.string("Object weight is:", LINE_3)
	weight = caculateWeight()	#get calculated weight from the calculateWeight function
	lcd.string(str(weight) + " grams", LINE_4)	#display the weight on the lcd

'''
*
* Function Name: 	tare
* Input: 				none
* Output: 			none
* Logic: 				takes the current weight of the object and stores it in variable then it will be subtracted form current weight value
* Example Call:		tare()
*
'''
def tare():
	"function to tare weight"
	global baseValue
	global taredWeight
	lcd.clear()
	lcd.string("Taring weight...", LINE_1)
	lcval = lc.read_average_value(10)
	diff = math.fabs(baseValue- lcval)
	taredWeight = (diff / 49000.0) * 230.0  #store the calculated weight in variable

'''
*
* Function Name: 	takePicture
* Input: 				none
* Output: 			none
* Logic: 				takes picture using USB camera using fscam program
* Example Call:		takePicture()
*
'''
def takePicture():
	"fucntion to take picture using USB camera"
	global imgName
	global pictureTaken
	lcd.string("Taking picture...", LINE_2)
	if os.path.exists('/dev/video0'):
		#create image file name with current date
		imgName = "image-" + datetime.datetime.now().isoformat() + ".jpg"
		#capture image and save in images directory. if image file does not exists in folder then retake the image
		while os.path.isfile("/var/www/data/images/%s" %imgName) == False:
			os.system("fswebcam -r 640x480 -S 10 --no-banner /var/www/data/images/%s" %imgName)
		pictureTaken = 1  #if picture is successfully taken then set pictureTaken flag to 1
	else:	#if camera is not attached display error message
		lcd.clear()
		lcd.string("      FAILED", LINE_1)
		lcd.string("No camera attached", LINE_2)
		time.sleep(3)

'''
*
* Function Name: 	storeData
* Input: 				none
* Output: 			none
* Logic: 				stores the data into local database
* Example Call:		storeData()
*
'''
def storeData():
	"fuction to store data in database"
	global imgName
	lcd.string("Storing data...", LINE_3)
	try:
		#create instance of a database with host, username, password and database name
		db = sqldb.connect(host, username, password, 'maindb')
		#create cursor object
		cursor = db.cursor()
		img_path = "./images/" + imgName
		#insert values in database. isoformat() will give mysql compatible datetime object
		cursor.execute("INSERT INTO data (troughid, cropid, name, date, weight, imagepath, location) VALUES (%s, %s, %s, %s, %s, %s, %s)", (troughID, cropID, cropName, datetime.datetime.now().isoformat(), measuredWeight, img_path, locationName))
		db.commit()  #commit the changes
		lcd.clear()
		#lcd.string("Successfully stored", LINE_1)
		#lcd.string("in local database", LINE_2)
		lcd.string("      Success", LINE_2)
		time.sleep(1)
	except:
		lcd.clear()
		#lcd.string("Failed to store", LINE_1)
		#lcd.string("in local database", LINE_2)
		lcd.string("      FAILED", LINE_1)
		time.sleep(3)
	db.close()

'''
*
* Function Name: 	fetchCropInfo
* Input: 				none
* Output: 			none
* Logic: 				fetches the crop name and id from local database
* Example Call:		fetchCropInfo()
*
'''
def fetchCropInfo():
	"retrieves crop info through cropid info"
	global cropID
	global cropName
	global cropIDExcepted
	try:
		lcd.clear()
		lcd.string("Fetching crop info...", LINE_1)
		#create instance of a database with host, username, password and database name
		db = sqldb.connect("localhost", "root", "firebird", "maindb")
		#create cursor object
		cursor = db.cursor()
		cid = int(cropID)  #convert accepted crop id into integer
		sql = "SELECT name FROM cropinfo WHERE id = %d" % (cid)
		cursor.execute(sql)
		data = cursor.fetchone()
		#if there some crop exists with this id
		if data > 0:
			cropName = data[0]  #then assigh cropname to variable
			cropIDExcepted = 1	#set cropIDExcepted flag to one
			#lcd.clear()
			#lcd.string("Successfully fetched", LINE_1)
			#lcd.string("crop information", LINE_2)
			#time.sleep(0.5)
		else:  #if no crop exists with entered ID
			lcd.clear()
			lcd.string("Crop ID does not", LINE_1)
			lcd.string("exists!", LINE_2)
			lcd.string("Enter valid crop ID", LINE_3)
			time.sleep(3)
	except:  #if database connection Fails
		lcd.clear()
		lcd.string("      FAILED", LINE_1)
		lcd.string("Unable to connect to", LINE_2)
		lcd.string("local database", LINE_3)
		lcd.string("Try again later", LINE_4)
		time.sleep(3)
	db.close()

'''
*
* Function Name: 	acceptCropID
* Input: 				none
* Output: 			none
* Logic: 				accepts crop ID from user using keypad
* Example Call:		acceptCropID()
*
'''
def acceptCropID():
	"function to accept crop through keypad"
	global cropID
	lcd.clear()
	cropID = ""
	key = ""
	time.sleep(0.1)

	lcd.string("Enter Crop ID", LINE_1)
	lcd.string("Press * to continue", LINE_2)
	lcd.string("and # for backspace", LINE_3)
	#loop until some crop id is entered and * key is pressed. Following loop will run until valid crop id entered
	while  key != "*":
		lcd.string(cropID, LINE_4)
		key = kpad.get_key()
		if key == '*':
			if len(cropID) <= 0:
				lcd.clear()
				lcd.string("Crop ID cant", LINE_1)
				lcd.string("be null", LINE_2)
				time.sleep(3)
				lcd.clear()
				lcd.string("Enter Crop ID", LINE_1)
				lcd.string("Press * to continue", LINE_2)
				lcd.string("and # for backspace", LINE_3)
			else:
				break
		elif key == '#':  #for backspacing
			if len(cropID) > 0:
				cropID = cropID[:-1]
		elif key.isdigit():
			cropID += key
			time.sleep(0.2)
		key = ""
	#after accepting crop ID fetch crop information from local database
	fetchCropInfo()
	
'''
*
* Function Name: 	fetchLocationInfo
* Input: 				none
* Output: 			none
* Logic: 				fetches the location name and id from local database
* Example Call:		fetchLocationInfo()
*
'''
def fetchLocationInfo():
	"retrieves location info through locationid info"
	global locationID
	global locationName
	global locationIDExcepted
	try:
		lcd.clear()
		lcd.string("Fetching location...", LINE_1)
		#create instance of a database with host, username, password and database name
		db = sqldb.connect("localhost", "root", "firebird", "maindb")
		#create cursor object
		cursor = db.cursor()
		lid = int(locationID)  #convert accepted location id into integer
		sql = "SELECT locationname FROM locationinfo WHERE locationid = %d" % (lid)
		cursor.execute(sql)
		data = cursor.fetchone()
		#if there some location exists with this id
		if data > 0:
			locationName = data[0]  #then assigh locationname to variable
			locationIDExcepted = 1	#set locationIDExcepted flag to one
			#lcd.clear()
			#lcd.string("Successfully fetched", LINE_1)
			#lcd.string("location information", LINE_2)
			#time.sleep(0.5)
		else:  #if no location exists with entered ID
			lcd.clear()
			lcd.string("location ID does not", LINE_1)
			lcd.string("exists!", LINE_2)
			lcd.string("Enter valid location", LINE_3)
			lcd.string("ID", LINE_4)
			time.sleep(3)
	except:  #if database connection Fails
		lcd.clear()
		lcd.string("      FAILED", LINE_1)
		lcd.string("Unable to connect to", LINE_2)
		lcd.string("local database", LINE_3)
		lcd.string("Try again later", LINE_4)
		time.sleep(3)
	db.close()


'''
*
* Function Name: 	acceptLocationID
* Input: 				none
* Output: 			none
* Logic: 				accepts location ID from user using keypad
* Example Call:		acceptLocationID()
*
'''
def acceptLocationID():
	"function to accept locationid through keypad"
	global locationID
	global locationIDExcepted
	lcd.clear()
	locationID = ""
	key = ""
	time.sleep(0.1)
	lcd.string("Enter Location ID", LINE_1)
	lcd.string("Press * to continue", LINE_2)
	lcd.string("and # for backspace", LINE_3)
	#loop until some location id is entered and * key is pressed. Following loop will only break when valid location ID is entered
	while  key != "*":
		lcd.string(locationID, LINE_4)
		key = kpad.get_key()
		if key == '*':
			if len(locationID) <= 0:
				lcd.clear()
				lcd.string("Location ID can't", LINE_1)
				lcd.string("be null", LINE_2)
				time.sleep(3)
				lcd.clear()
				lcd.string("Enter Location ID", LINE_1)
				lcd.string("Press * to continue", LINE_2)
				lcd.string("and # for backspace", LINE_3)
			else:
				break
		elif key == '#':  #for backspacing
			if len(locationID) > 0:
				locationID = locationID[:-1]
		elif key.isdigit():
			locationID += key
			time.sleep(0.1)
		key = ""
	#after accepting locationID fetch location info from local database
	fetchLocationInfo()

'''
*
* Function Name: 	fetchTroughInfo
* Input: 				none
* Output: 			none
* Logic: 				fetches the trough name and id from local database
* Example Call:		fetchTroughInfo()
*
'''
def fetchTroughInfo():
	"checks id entered troughid is valid of not"
	global troughID
	global troughIDExcepted
	try:
		lcd.clear()
		lcd.string("Fetching trough id...", LINE_1)
		#create instance of a database with host, username, password and database name
		db = sqldb.connect("localhost", "root", "firebird", "maindb")
		#create cursor object
		cursor = db.cursor()
		tid = int(troughID)  #convert accepted trough id into integer
		sql = "SELECT troughid FROM troughinfo WHERE troughid = %d" % (tid)
		cursor.execute(sql)
		data = cursor.fetchone()
		#if entered trough ID is valid
		if data > 0:
			troughIDExcepted = 1	#set troughIDExcepted flag to one
		else:  #if no trough id exists with entered ID
			lcd.clear()
			lcd.string("trough ID does not", LINE_1)
			lcd.string("exists!", LINE_2)
			lcd.string("Enter valid trough", LINE_3)
			lcd.string("ID", LINE_4)
			time.sleep(3)
	except:  #if database connection Fails
		lcd.clear()
		lcd.string("      FAILED", LINE_1)
		lcd.string("Unable to connect to", LINE_2)
		lcd.string("local database", LINE_3)
		lcd.string("Try again later", LINE_4)
		time.sleep(3)
	db.close()


'''
*
* Function Name: 	acceptTroughID
* Input: 				none
* Output: 			none
* Logic: 				accepts trough ID from user using keypad
* Example Call:		acceptTroughID()
*
'''
def acceptTroughID():
	"function to accept troughid through keypad"
	global troughID
	global troughIDExcepted
	lcd.clear()
	troughID = ""
	key = ""
	time.sleep(0.1)
	lcd.string("Enter Trough ID", LINE_1)
	lcd.string("Press * to continue", LINE_2)
	lcd.string("and # for backspace", LINE_3)
	#loop until some trough id is entered and * key is pressed. Following loop will only break when valid trough ID is entered
	while  key != "*":
		lcd.string(troughID, LINE_4)
		key = kpad.get_key()
		if key == '*':
			if len(troughID) <= 0:
				lcd.clear()
				lcd.string("Trough ID can't", LINE_1)
				lcd.string("be null", LINE_2)
				time.sleep(3)
				lcd.clear()
				lcd.string("Enter Trough ID", LINE_1)
				lcd.string("Press * to continue", LINE_2)
				lcd.string("and # for backspace", LINE_3)
			else:
				break
		elif key == '#':  #for backspacing
			if len(troughID) > 0:
				troughID = troughID[:-1]
		elif key.isdigit():
			troughID += key
			time.sleep(0.1)
		key = ""
	#check if entered trough ID is valid or not by fetching it from local database
	fetchTroughInfo()

'''
*
* Function Name: 	fetchTroughInfoFromServer
* Input: 				none
* Output: 			none
* Logic: 				fetches newly added or removed trough info from server database
* Example Call:		fetchTroughInfoFromServer()
*
'''
def fetchTroughInfoFromServer():
	"fetch newly added troughinfo such as id from the server"
	updated = 0
	removed = 0
	lcd.clear()
	lcd.string("      Welcome", LINE_1)
	lcd.string("Fetching troughinfo...", LINE_2)
	try:
		lcd.string("Connect to database", LINE_3)
		#connect to server database to fetch information
		serverdb = sqldb.connect(host = server, user = "bhavesh", passwd = "123456789", db = "opencart", connect_timeout = 5)
		#connect to local databse to store fetched information
		localdb = sqldb.connect("localhost", "root", "firebird", "maindb")
		serverc = serverdb.cursor()
		localc = localdb.cursor()
		lcd.string("     Connected", LINE_4)
		serverc.execute("SELECT troughid FROM troughinfo")
		result = serverc.fetchall()  #fetch all trough information form server database
		for row in result:
			localc.execute("SELECT * FROM troughinfo WHERE troughid = %s", (row[0]))  #fetch the trough info from local database with selected server trough id
			count = localc.fetchall()
			if len(count) == 0:  #if trough info does not exists in the server then count will be zero so add it in local database
				localc.execute("INSERT INTO troughinfo(troughid) VALUES (%s)", (row[0]))
				updated += 1

		localc.execute( "SELECT troughid FROM troughinfo")  #fetch all the local trough information
		lresult = localc.fetchall()

		for lrow in lresult:
			count = 0
			for row in result:
				if lrow[0] == row[0]: #if there is trough which is in both server and local database then this condition will be true.
					count += 1
			if count == 0:  #if there is some row in local database wich does not exists in server database then count will be zero then remove the entry from local database
				localc.execute("DELETE FROM troughinfo WHERE troughid = %s", (lrow[0]))
				removed += 1

		localdb.commit()
		lcd.clear()
		lcd.string("      Success", LINE_2)
		if updated > 0:
			msg = str(updated)
			msg += " trough id updated"
			lcd.string(msg, LINE_3)
			time.sleep(3)
		if removed > 0:
			msg = str(removed)
			msg += " trough id removed"
			lcd.string(msg, LINE_3)
			time.sleep(3)
		serverdb.close()
		localdb.close()
	except:
		#localdb.rollback()
		lcd.clear()
		lcd.string("      Failed to", LINE_2)
		lcd.string("   fetch troughinfo", LINE_3)
		time.sleep(3)

'''
*
* Function Name: 	fetchLocationInfoFromServer
* Input: 				none
* Output: 			none
* Logic: 				fetches the newly added or removed location from server database
* Example Call:		fetchLocationInfoFromServer()
*
'''
def fetchLocationInfoFromServer():
	"fetch newly added locationinfo such as id and locationname from the server"
	updated = 0
	removed = 0
	lcd.clear()
	lcd.string("      Welcome", LINE_1)
	lcd.string("Fetching locationinfo...", LINE_2)
	try:
		lcd.string("Connect to database", LINE_3)
		#connect to server database to fetch information
		serverdb = sqldb.connect(host = server, user = "bhavesh", passwd = "123456789", db = "opencart", connect_timeout = 5)
		#connect to local databse to store fetched information
		localdb = sqldb.connect("localhost", "root", "firebird", "maindb")
		serverc = serverdb.cursor()
		localc = localdb.cursor()
		lcd.string("     Connected", LINE_4)
		serverc.execute("SELECT * FROM locationinfo")
		result = serverc.fetchall()  #fetch all location information form server database
		for row in result:
			localc.execute("SELECT * FROM locationinfo WHERE locationid = %s", (row[0]))  #fetch the location info from local database with selected server location id
			count = localc.fetchall()
			if len(count) == 0:  #if location does not exists in the server then count will be zero so add it in local database
				localc.execute("INSERT INTO locationinfo(locationid, locationname) VALUES (%s, %s)", (row[0], row[1]))
				updated += 1

		localc.execute( "SELECT locationid FROM locationinfo")  #fetch all the local location information
		lresult = localc.fetchall()

		for lrow in lresult:
			count = 0
			for row in result:
				if lrow[0] == row[0]: #if there is location which is in both server and local database then this condition will be true.
					count += 1
			if count == 0:  #if there is some row in local database wich does not exists in server database then count will be zero then remove the entry from local database
				localc.execute("DELETE FROM locationinfo WHERE locationid = %s", (lrow[0]))
				removed += 1

		localdb.commit()
		lcd.clear()
		lcd.string("      Success", LINE_2)
		if updated > 0:
			msg = str(updated)
			msg += " location updated"
			lcd.string(msg, LINE_3)
			time.sleep(3)
		if removed > 0:
			msg = str(removed)
			msg += " location removed"
			lcd.string(msg, LINE_3)
			time.sleep(3)
		serverdb.close()
		localdb.close()
	except:
		#localdb.rollback()
		lcd.clear()
		lcd.string("      Failed to", LINE_2)
		lcd.string("   fetch locationinfo", LINE_3)
		time.sleep(3)
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

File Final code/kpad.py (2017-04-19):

import RPi.GPIO as GPIO
import time
GPIO.setmode(GPIO.BOARD)
GPIO.setwarnings(False)


def get_key ():
	MATRIX=[ [1,2,3,'A'],
	 [4,5,6,'B'],
	 [7,8,9,'C'],
	 ['*',0,'#','D']
	]
	MATRIX2=[ [1,1,1,1],
	 [1,1,1,1],
	 [1,1,1,1],
	 [1,1,1,1]
	]

	ROW=[29,31,33,35]
	COL=[18,40, 38, 36]

	for j in range(4):
		GPIO.setup(COL[j],GPIO.OUT)
		GPIO.output(COL[j],1)

	for i in range(4):
		GPIO.setup(ROW[i],GPIO.IN,pull_up_down=GPIO.PUD_UP)
	k=0
	n=0
	m=0
	x=1
	result='E'


	for j in range(4):

		GPIO.output(COL[j],0)
	        for i in range(4):
		      cstate=1
		      if m==i and n==j and x!=1:
		        cstate=MATRIX2[m][n]

		      count=0
		      k=0
		      x=0

		      while k<14:

		   		recieve=GPIO.input(ROW[i])
				if recieve == cstate and count>0:
					count = count-1
				if recieve != cstate:
					count = count+1

				if count >=10:
					count = 0
					cstate=recieve
					m=i
					n=j
					MATRIX2=[[1,1,1,1], [1,1,1,1],[1,1,1,1],[1,1,1,1]]
					MATRIX2[m][n]=cstate
					if cstate==0:
						#print MATRIX[i][j]
						result= MATRIX[i][j]
		       		k=k+1

		GPIO.output(COL[j],1)
	return str(result)
